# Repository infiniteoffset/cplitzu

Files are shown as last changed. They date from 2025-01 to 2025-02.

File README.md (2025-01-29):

# Cplitzu keyboard

The Cplitzu Keyboard is a compact, ortholinear, 50-key split keyboard inspired by the [Let's split](https://github.com/nicinabox/lets-split-guide) and [Corne](https://github.com/foostan/crkbd) keyboards. It features a 3x6 ortholinear layout with an additional thumb key for improved ergonomics and functionality. Designed with ease of assembly in mind, it avoids the need for tiny SMD components, making it beginner-friendly for hand soldering.

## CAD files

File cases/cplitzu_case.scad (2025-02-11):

$fn=64; 

// https://github.com/Irev-Dev/Round-Anything/
include <Round-Anything/polyround.scad>

pcbx = 19.05*7; // pcb width
pcby = 19.05*4; // pcb length

inscl = 0.2; // inside clearance from pcb

inhgt = 14.5; // inside height

cwt = 3.5; //case wall thickness
cbt = 2.5; //case bottom thickness

module case_inside(){
    sketchPoints=[
        [-inscl, -inscl,  1.5],
        [-inscl, pcby+inscl, 1.5],
        [pcbx+inscl,  pcby+inscl,  1.5],
        [pcbx+inscl,  -inscl,  1.5]
    ];
    polyRoundExtrude(
        sketchPoints,
        inhgt+0.1,
        r1=-0.5,
        r2=0.5,
        fn=$fn
    );
}

module case_outside(){
    sketchPoints=[
        [-inscl - cwt, -inscl - cwt,  5],
        [-inscl - cwt, pcby + inscl + cwt, 5],
        [pcbx + inscl + cwt,  pcby + inscl + cwt,  5],
        [pcbx + inscl + cwt,  -inscl - cwt,  5]
    ];
    translate([0, 0, -cbt])
    polyRoundExtrude(
        sketchPoints,
        inhgt + cbt,
        r1=2.5,
        r2=2.5,
        fn=$fn
    );
}

module case_body(){
    difference() {
        case_outside();
        case_inside();
    }
}

module mounting_hole(x=0, y=0){
    translate([x,y,-cbt-0.01]){
        cylinder(h=cbt+0.02, d=2.4);
        cylinder(h=1.5, d1= 4.4, d2=2.4);
    }
}

module foot_hole(x=0, y=0){
    translate([x,y,-cbt-0.01]){
        cylinder(h=1+0.01, d=8.8);
    }
}

module usbc_hole(x=0, y=0){
    translate([x,y,7.5])
    rotate([-90,0,0])
    hull(){
        translate([3.5,0,-0.01])
            cylinder(d=6.5, h=cwt+0.02);
        translate([-3.5,0,-0.01])
            cylinder(d=6.5, h=cwt+0.02);
    }
}



module trrs_hole(x=0, y=0){
    translate([x,y,6.15])
    rotate([0,90,0])
    translate([0,0,-0.01])
        cylinder(d=7, h=cwt+0.02);
}


module case(){
    difference(){
        case_body();
        
        mounting_hole(19.05*1,19.05*1);
        mounting_hole(19.05*1,19.05*3);
        mounting_hole(19.05*5,19.05*1);
        mounting_hole(19.05*5,19.05*3);
        
        //foot_hole(4,4);
        //foot_hole(4,pcby-4);
        //foot_hole(pcbx-4,pcby-4);
        //foot_hole(pcbx-4,4);
        
        trrs_hole(pcbx + inscl, 28.57);
        usbc_hole(123.15,pcby + inscl);
    }
}

//mirror([1,0,0])
case();

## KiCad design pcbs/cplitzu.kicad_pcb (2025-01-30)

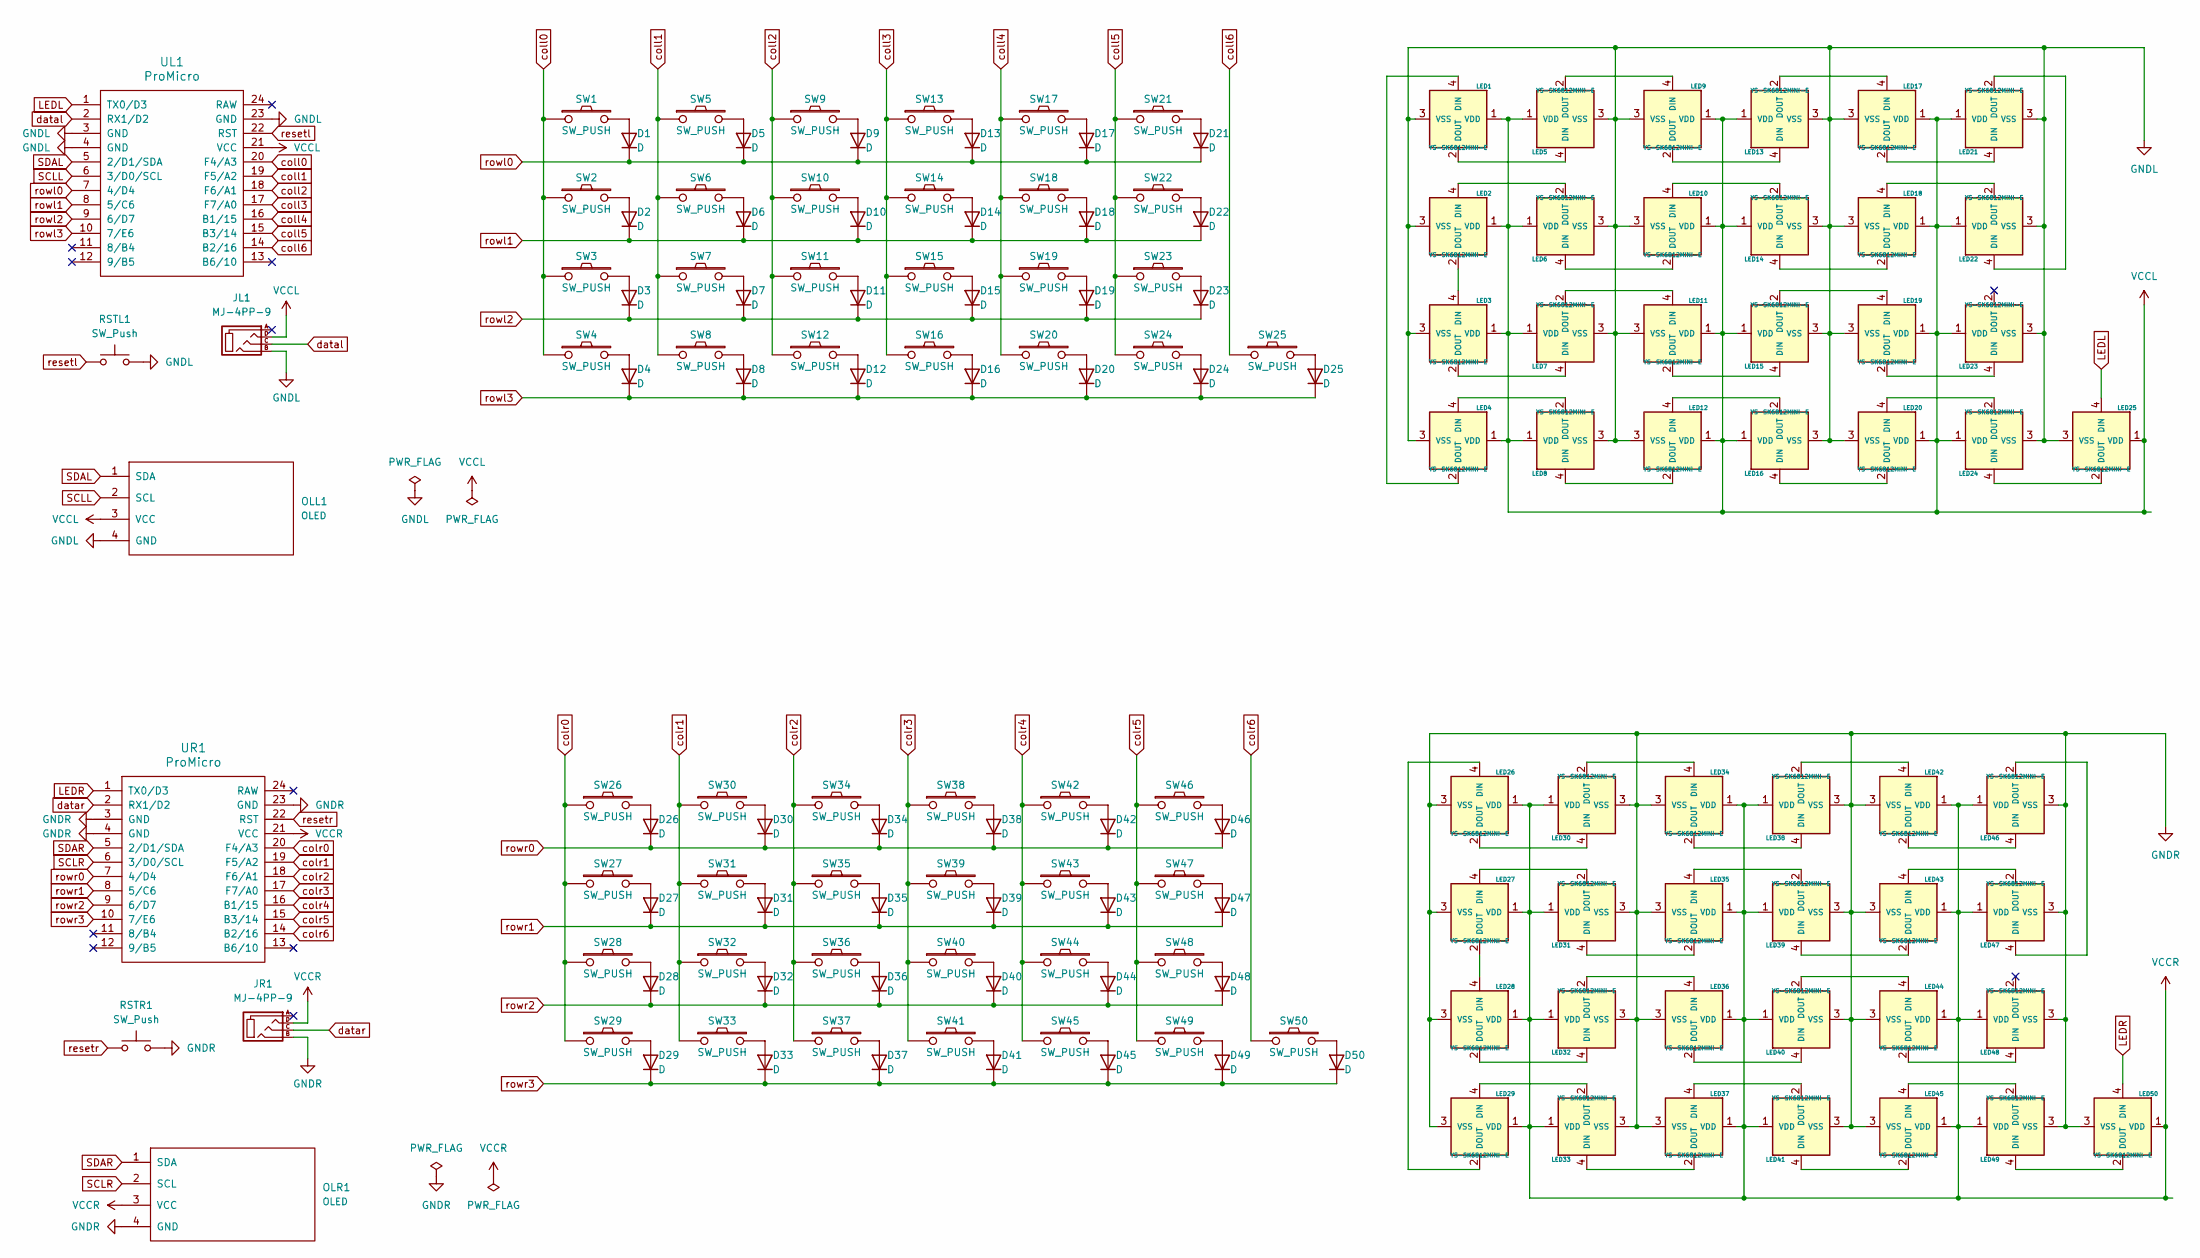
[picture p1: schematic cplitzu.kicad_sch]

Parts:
D1, D2, D3, D4, D5, D6, D7, D8, D9, D10, D11, D12, D13, D14, D15, D16, D17, D18, D19, D20, D21, D22, D23, D24, D25, D26, D27, D28, D29, D30, D31, D32, D33, D34, D35, D36, D37, D38, D39, D40, D41, D42, D43, D44, D45, D46, D47, D48, D49, D50: D; D_DO-35_SOD27_P7.62mm_Horizontal
JL1: MJ-4PP-9
JR1: MJ-4PP-9
LED1, LED2, LED3, LED4, LED5, LED6, LED7, LED8, LED9, LED10, LED11, LED12, LED13, LED14, LED15, LED16, LED17, LED18, LED19, LED20, LED21, LED22, LED23, LED24, LED25, LED26, LED27, LED28, LED29, LED30, LED31, LED32, LED33, LED34, LED35, LED36, LED37, LED38, LED39, LED40, LED41, LED42, LED43, LED44, LED45, LED46, LED47, LED48, LED49, LED50: YS-SK6812MINI-E
OLL1: OLED
OLR1: OLED
RSTL1: SW_Push; ResetSW
RSTR1: SW_Push; ResetSW
SW1, SW2, SW3, SW4, SW5, SW6, SW7, SW8, SW9, SW10, SW11, SW12, SW13, SW14, SW15, SW16, SW17, SW18, SW19, SW20, SW21, SW22, SW23, SW24, SW25, SW26, SW27, SW28, SW29, SW30, SW31, SW32, SW33, SW34, SW35, SW36, SW37, SW38, SW39, SW40, SW41, SW42, SW43, SW44, SW45, SW46, SW47, SW48, SW49, SW50: SW_PUSH; keyswitch_cherrymx_hotswap_1u
UL1: ProMicro
UR1: ProMicro

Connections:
GNDL: JL1.B, LED1.3 (VSS), LED2.3 (VSS), LED3.3 (VSS), LED4.3 (VSS), LED5.3 (VSS), LED6.3 (VSS), LED7.3 (VSS), LED8.3 (VSS), LED9.3 (VSS), LED10.3 (VSS), LED11.3 (VSS), LED12.3 (VSS), LED13.3 (VSS), LED14.3 (VSS), LED15.3 (VSS), LED16.3 (VSS), LED17.3 (VSS), LED18.3 (VSS), LED19.3 (VSS), LED20.3 (VSS), LED21.3 (VSS), LED22.3 (VSS), LED23.3 (VSS), LED24.3 (VSS), LED25.3 (VSS), OLL1.4 (GND), RSTL1.2, UL1.3 (GND), UL1.4 (GND), UL1.23 (GND)
GNDR: JR1.B, LED26.3 (VSS), LED27.3 (VSS), LED28.3 (VSS), LED29.3 (VSS), LED30.3 (VSS), LED31.3 (VSS), LED32.3 (VSS), LED33.3 (VSS), LED34.3 (VSS), LED35.3 (VSS), LED36.3 (VSS), LED37.3 (VSS), LED38.3 (VSS), LED39.3 (VSS), LED40.3 (VSS), LED41.3 (VSS), LED42.3 (VSS), LED43.3 (VSS), LED44.3 (VSS), LED45.3 (VSS), LED46.3 (VSS), LED47.3 (VSS), LED48.3 (VSS), LED49.3 (VSS), LED50.3 (VSS), OLR1.4 (GND), RSTR1.2, UR1.3 (GND), UR1.4 (GND), UR1.23 (GND)
LEDL: LED25.4 (DIN), UL1.1 (TX0/D3)
LEDR: LED50.4 (DIN), UR1.1 (TX0/D3)
unnamed: D1.2 (A), SW1.2
unnamed: D2.2 (A), SW2.2
unnamed: D3.2 (A), SW3.2
unnamed: D4.2 (A), SW4.2
unnamed: D5.2 (A), SW5.2
unnamed: D6.2 (A), SW6.2
unnamed: D7.2 (A), SW7.2
unnamed: D8.2 (A), SW8.2
unnamed: D9.2 (A), SW9.2
unnamed: D10.2 (A), SW10.2
unnamed: D11.2 (A), SW11.2
unnamed: D12.2 (A), SW12.2
unnamed: D13.2 (A), SW13.2
unnamed: D14.2 (A), SW14.2
unnamed: D15.2 (A), SW15.2
unnamed: D16.2 (A), SW16.2
unnamed: D17.2 (A), SW17.2
unnamed: D18.2 (A), SW18.2
unnamed: D19.2 (A), SW19.2
unnamed: D20.2 (A), SW20.2
unnamed: D21.2 (A), SW21.2
unnamed: D22.2 (A), SW22.2
unnamed: D23.2 (A), SW23.2
unnamed: D24.2 (A), SW24.2
unnamed: D25.2 (A), SW25.2
unnamed: D26.2 (A), SW26.2
unnamed: D27.2 (A), SW27.2
unnamed: D28.2 (A), SW28.2
unnamed: D29.2 (A), SW29.2
unnamed: D30.2 (A), SW30.2
unnamed: D31.2 (A), SW31.2
unnamed: D32.2 (A), SW32.2
unnamed: D33.2 (A), SW33.2
unnamed: D34.2 (A), SW34.2
unnamed: D35.2 (A), SW35.2
unnamed: D36.2 (A), SW36.2
unnamed: D37.2 (A), SW37.2
unnamed: D38.2 (A), SW38.2
unnamed: D39.2 (A), SW39.2
unnamed: D40.2 (A), SW40.2
unnamed: D41.2 (A), SW41.2
unnamed: D42.2 (A), SW42.2
unnamed: D43.2 (A), SW43.2
unnamed: D44.2 (A), SW44.2
unnamed: D45.2 (A), SW45.2
unnamed: D46.2 (A), SW46.2
unnamed: D47.2 (A), SW47.2
unnamed: D48.2 (A), SW48.2
unnamed: D49.2 (A), SW49.2
unnamed: D50.2 (A), SW50.2
unnamed: LED1.4 (DIN), LED4.2 (DOUT)
unnamed: LED1.2 (DOUT), LED5.4 (DIN)
unnamed: LED2.4 (DIN), LED6.2 (DOUT)
unnamed: LED2.2 (DOUT), LED3.4 (DIN)
unnamed: LED3.2 (DOUT), LED7.4 (DIN)
unnamed: LED4.4 (DIN), LED8.2 (DOUT)
unnamed: LED5.2 (DOUT), LED9.4 (DIN)
unnamed: LED10.4 (DIN), LED14.2 (DOUT)
unnamed: LED6.4 (DIN), LED10.2 (DOUT)
unnamed: LED7.2 (DOUT), LED11.4 (DIN)
unnamed: LED11.2 (DOUT), LED15.4 (DIN)
unnamed: LED12.4 (DIN), LED16.2 (DOUT)
unnamed: LED8.4 (DIN), LED12.2 (DOUT)
unnamed: LED9.2 (DOUT), LED13.4 (DIN)
unnamed: LED13.2 (DOUT), LED17.4 (DIN)
unnamed: LED14.4 (DIN), LED18.2 (DOUT)
unnamed: LED15.2 (DOUT), LED19.4 (DIN)
unnamed: LED16.4 (DIN), LED20.2 (DOUT)
unnamed: LED17.2 (DOUT), LED21.4 (DIN)
unnamed: LED18.4 (DIN), LED22.2 (DOUT)
unnamed: LED19.2 (DOUT), LED23.4 (DIN)
unnamed: LED20.4 (DIN), LED24.2 (DOUT)
unnamed: LED21.2 (DOUT), LED22.4 (DIN)
unnamed: LED24.4 (DIN), LED25.2 (DOUT)
unnamed: LED26.4 (DIN), LED29.2 (DOUT)
unnamed: LED26.2 (DOUT), LED30.4 (DIN)
unnamed: LED27.4 (DIN), LED31.2 (DOUT)
unnamed: LED27.2 (DOUT), LED28.4 (DIN)
unnamed: LED28.2 (DOUT), LED32.4 (DIN)
unnamed: LED29.4 (DIN), LED33.2 (DOUT)
unnamed: LED30.2 (DOUT), LED34.4 (DIN)
unnamed: LED31.4 (DIN), LED35.2 (DOUT)
unnamed: LED32.2 (DOUT), LED36.4 (DIN)
unnamed: LED33.4 (DIN), LED37.2 (DOUT)
unnamed: LED34.2 (DOUT), LED38.4 (DIN)
unnamed: LED35.4 (DIN), LED39.2 (DOUT)
unnamed: LED36.2 (DOUT), LED40.4 (DIN)
unnamed: LED37.4 (DIN), LED41.2 (DOUT)
unnamed: LED38.2 (DOUT), LED42.4 (DIN)
unnamed: LED39.4 (DIN), LED43.2 (DOUT)
unnamed: LED40.2 (DOUT), LED44.4 (DIN)
unnamed: LED41.4 (DIN), LED45.2 (DOUT)
unnamed: LED42.2 (DOUT), LED46.4 (DIN)
unnamed: LED43.4 (DIN), LED47.2 (DOUT)
unnamed: LED44.2 (DOUT), LED48.4 (DIN)
unnamed: LED45.4 (DIN), LED49.2 (DOUT)
unnamed: LED46.2 (DOUT), LED47.4 (DIN)
unnamed: LED49.4 (DIN), LED50.2 (DOUT)
SCLL: OLL1.2 (SCL), UL1.6 (3/D0/SCL)
SCLR: OLR1.2 (SCL), UR1.6 (3/D0/SCL)
SDAL: OLL1.1 (SDA), UL1.5 (2/D1/SDA)
SDAR: OLR1.1 (SDA), UR1.5 (2/D1/SDA)
VCCL: JL1.D, LED1.1 (VDD), LED2.1 (VDD), LED3.1 (VDD), LED4.1 (VDD), LED5.1 (VDD), LED6.1 (VDD), LED7.1 (VDD), LED8.1 (VDD), LED9.1 (VDD), LED10.1 (VDD), LED11.1 (VDD), LED12.1 (VDD), LED13.1 (VDD), LED14.1 (VDD), LED15.1 (VDD), LED16.1 (VDD), LED17.1 (VDD), LED18.1 (VDD), LED19.1 (VDD), LED20.1 (VDD), LED21.1 (VDD), LED22.1 (VDD), LED23.1 (VDD), LED24.1 (VDD), LED25.1 (VDD), OLL1.3 (VCC), UL1.21 (VCC)
VCCR: JR1.D, LED26.1 (VDD), LED27.1 (VDD), LED28.1 (VDD), LED29.1 (VDD), LED30.1 (VDD), LED31.1 (VDD), LED32.1 (VDD), LED33.1 (VDD), LED34.1 (VDD), LED35.1 (VDD), LED36.1 (VDD), LED37.1 (VDD), LED38.1 (VDD), LED39.1 (VDD), LED40.1 (VDD), LED41.1 (VDD), LED42.1 (VDD), LED43.1 (VDD), LED44.1 (VDD), LED45.1 (VDD), LED46.1 (VDD), LED47.1 (VDD), LED48.1 (VDD), LED49.1 (VDD), LED50.1 (VDD), OLR1.3 (VCC), UR1.21 (VCC)
coll0: SW1.1, SW2.1, SW3.1, SW4.1, UL1.20 (F4/A3)
coll1: SW5.1, SW6.1, SW7.1, SW8.1, UL1.19 (F5/A2)
coll2: SW9.1, SW10.1, SW11.1, SW12.1, UL1.18 (F6/A1)
coll3: SW13.1, SW14.1, SW15.1, SW16.1, UL1.17 (F7/A0)
coll4: SW17.1, SW18.1, SW19.1, SW20.1, UL1.16 (B1/15)
coll5: SW21.1, SW22.1, SW23.1, SW24.1, UL1.15 (B3/14)
coll6: SW25.1, UL1.14 (B2/16)
colr0: SW26.1, SW27.1, SW28.1, SW29.1, UR1.20 (F4/A3)
colr1: SW30.1, SW31.1, SW32.1, SW33.1, UR1.19 (F5/A2)
colr2: SW34.1, SW35.1, SW36.1, SW37.1, UR1.18 (F6/A1)
colr3: SW38.1, SW39.1, SW40.1, SW41.1, UR1.17 (F7/A0)
colr4: SW42.1, SW43.1, SW44.1, SW45.1, UR1.16 (B1/15)
colr5: SW46.1, SW47.1, SW48.1, SW49.1, UR1.15 (B3/14)
colr6: SW50.1, UR1.14 (B2/16)
datal: JL1.C, UL1.2 (RX1/D2)
datar: JR1.C, UR1.2 (RX1/D2)
resetl: RSTL1.1, UL1.22 (RST)
resetr: RSTR1.1, UR1.22 (RST)
rowl0: D1.1 (K), D5.1 (K), D9.1 (K), D13.1 (K), D17.1 (K), D21.1 (K), UL1.7 (4/D4)
rowl1: D2.1 (K), D6.1 (K), D10.1 (K), D14.1 (K), D18.1 (K), D22.1 (K), UL1.8 (5/C6)
rowl2: D3.1 (K), D7.1 (K), D11.1 (K), D15.1 (K), D19.1 (K), D23.1 (K), UL1.9 (6/D7)
rowl3: D4.1 (K), D8.1 (K), D12.1 (K), D16.1 (K), D20.1 (K), D24.1 (K), D25.1 (K), UL1.10 (7/E6)
rowr0: D26.1 (K), D30.1 (K), D34.1 (K), D38.1 (K), D42.1 (K), D46.1 (K), UR1.7 (4/D4)
rowr1: D27.1 (K), D31.1 (K), D35.1 (K), D39.1 (K), D43.1 (K), D47.1 (K), UR1.8 (5/C6)
rowr2: D28.1 (K), D32.1 (K), D36.1 (K), D40.1 (K), D44.1 (K), D48.1 (K), UR1.9 (6/D7)
rowr3: D29.1 (K), D33.1 (K), D37.1 (K), D41.1 (K), D45.1 (K), D49.1 (K), D50.1 (K), UR1.10 (7/E6)

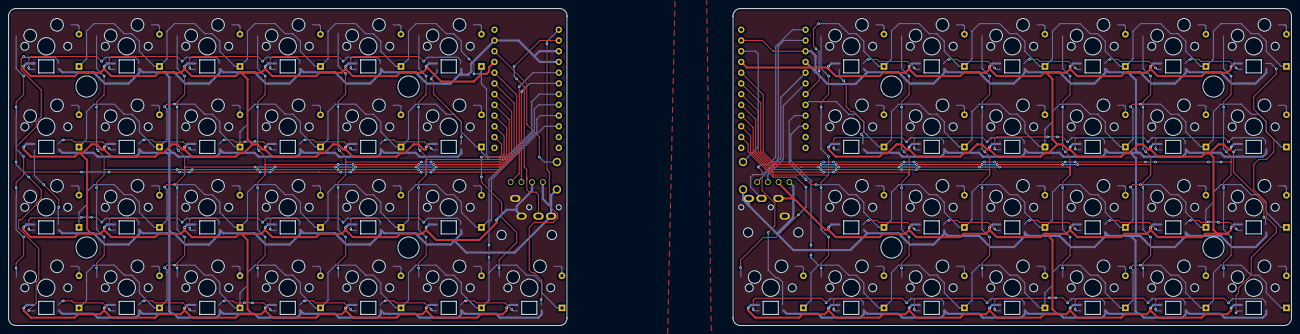
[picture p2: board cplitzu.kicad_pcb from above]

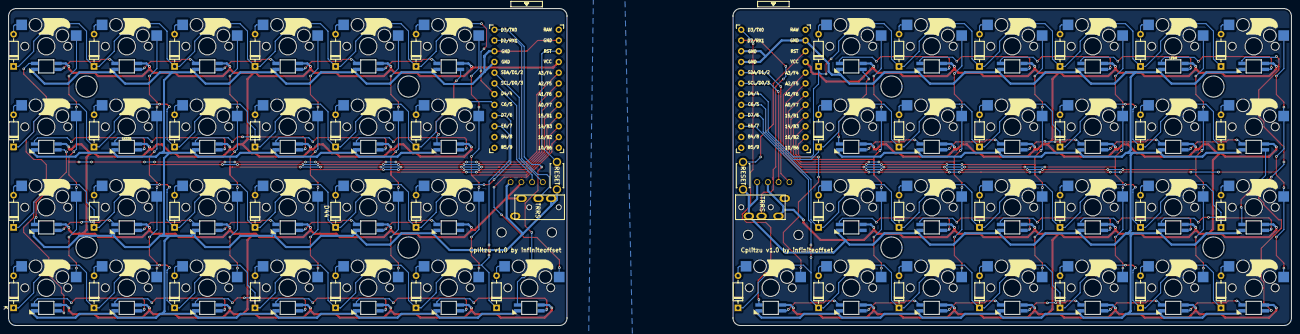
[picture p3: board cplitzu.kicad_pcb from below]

Board: 2 copper layers, 303.6 x 75.0 mm, 158 parts (150 on the bottom side), 134 nets.

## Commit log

2025-01-30 create pcbs v1.0
    [cplitzu.kicad_pcb, cplitzu.kicad_sch]
2025-01-30 rename gerbers
2025-01-30 create plates
    [cplitzu_plates.kicad_pcb, cplitzu_plates.kicad_sch]
2025-01-31 create cases
    [cplitzu_case.scad]
2025-02-11 change case dimensions and remove feet holes
    [cplitzu_case.scad]
